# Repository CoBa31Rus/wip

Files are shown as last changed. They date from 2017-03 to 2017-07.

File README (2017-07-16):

Терморегулятор для инкубатора в стадии разработки.
Построен на atmega8 + LCD1602, 3 кнопки, 3 транзистора один из которых задействован как ШИМ.
Схема пока что тестируется
Цель: создание терморегулятора для инкубатора, возможно с дополнительными ф-ями(переворот, влажность....)
Чем отличаемся от тясячь других? Нужен регулятор который может работать от 12в т.к. используется там где могут отключать свет долгосрочно

Цели:
  1. ~~Перенос опроса DS18B20 на таймер вместо задержек.~~
  2. Обновление данных на экране по мере поступления.
  3. ~~Реализация ПИД регулятора.~~
  4. ~~Вывод параметров в виде простого меню.~~
  5. ~~Редактирование параметров.~~
  6. ~~Сохранение параметров в EEPROM~~
  7. Generate EEPROM from make

Change:
  16.07.2017
	1.Delete eeprom.c eeprom.h (Use from std AVR library)
	2.Delete old Makefile (work fine)
	3.Fix main.c for new eeprom func
	4.Add eeprom create and upload
  12.07.2017
  	1. New Makefile, generate by standart WinAVR Mfile.
	2. Fix warning with lcd.h
	3. add #DEBUG for global val pid
	4. add generate eeprom (but now is empty)
  25.06.2017
  	1. fix bug's with PID (now PID is work normal)
	2. add function "DEBUG" with USART (send temp for change PID coefficient, just Define DEBUG)
	
  26.03.2017:
	1. add hardware
	2. modify hardware
  22.04.2017
	1. Fix temperature bug
	2. Size 4.3 -> 2.6
	3. Delete sprintf
	4. New onewire files

!!PS!! Sorry for my English =)

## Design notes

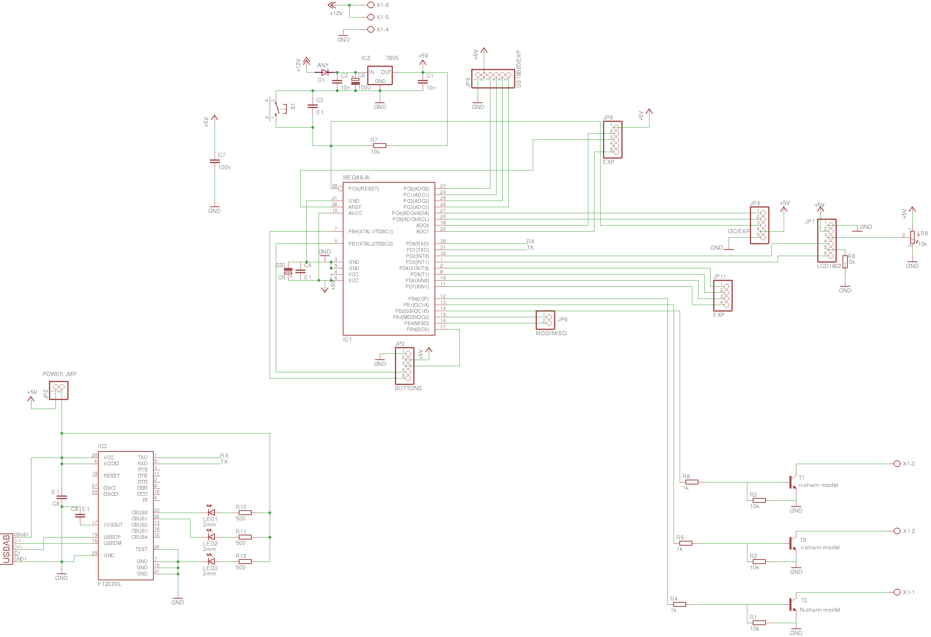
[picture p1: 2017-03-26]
LCD+DS18B20/hardware/img.png

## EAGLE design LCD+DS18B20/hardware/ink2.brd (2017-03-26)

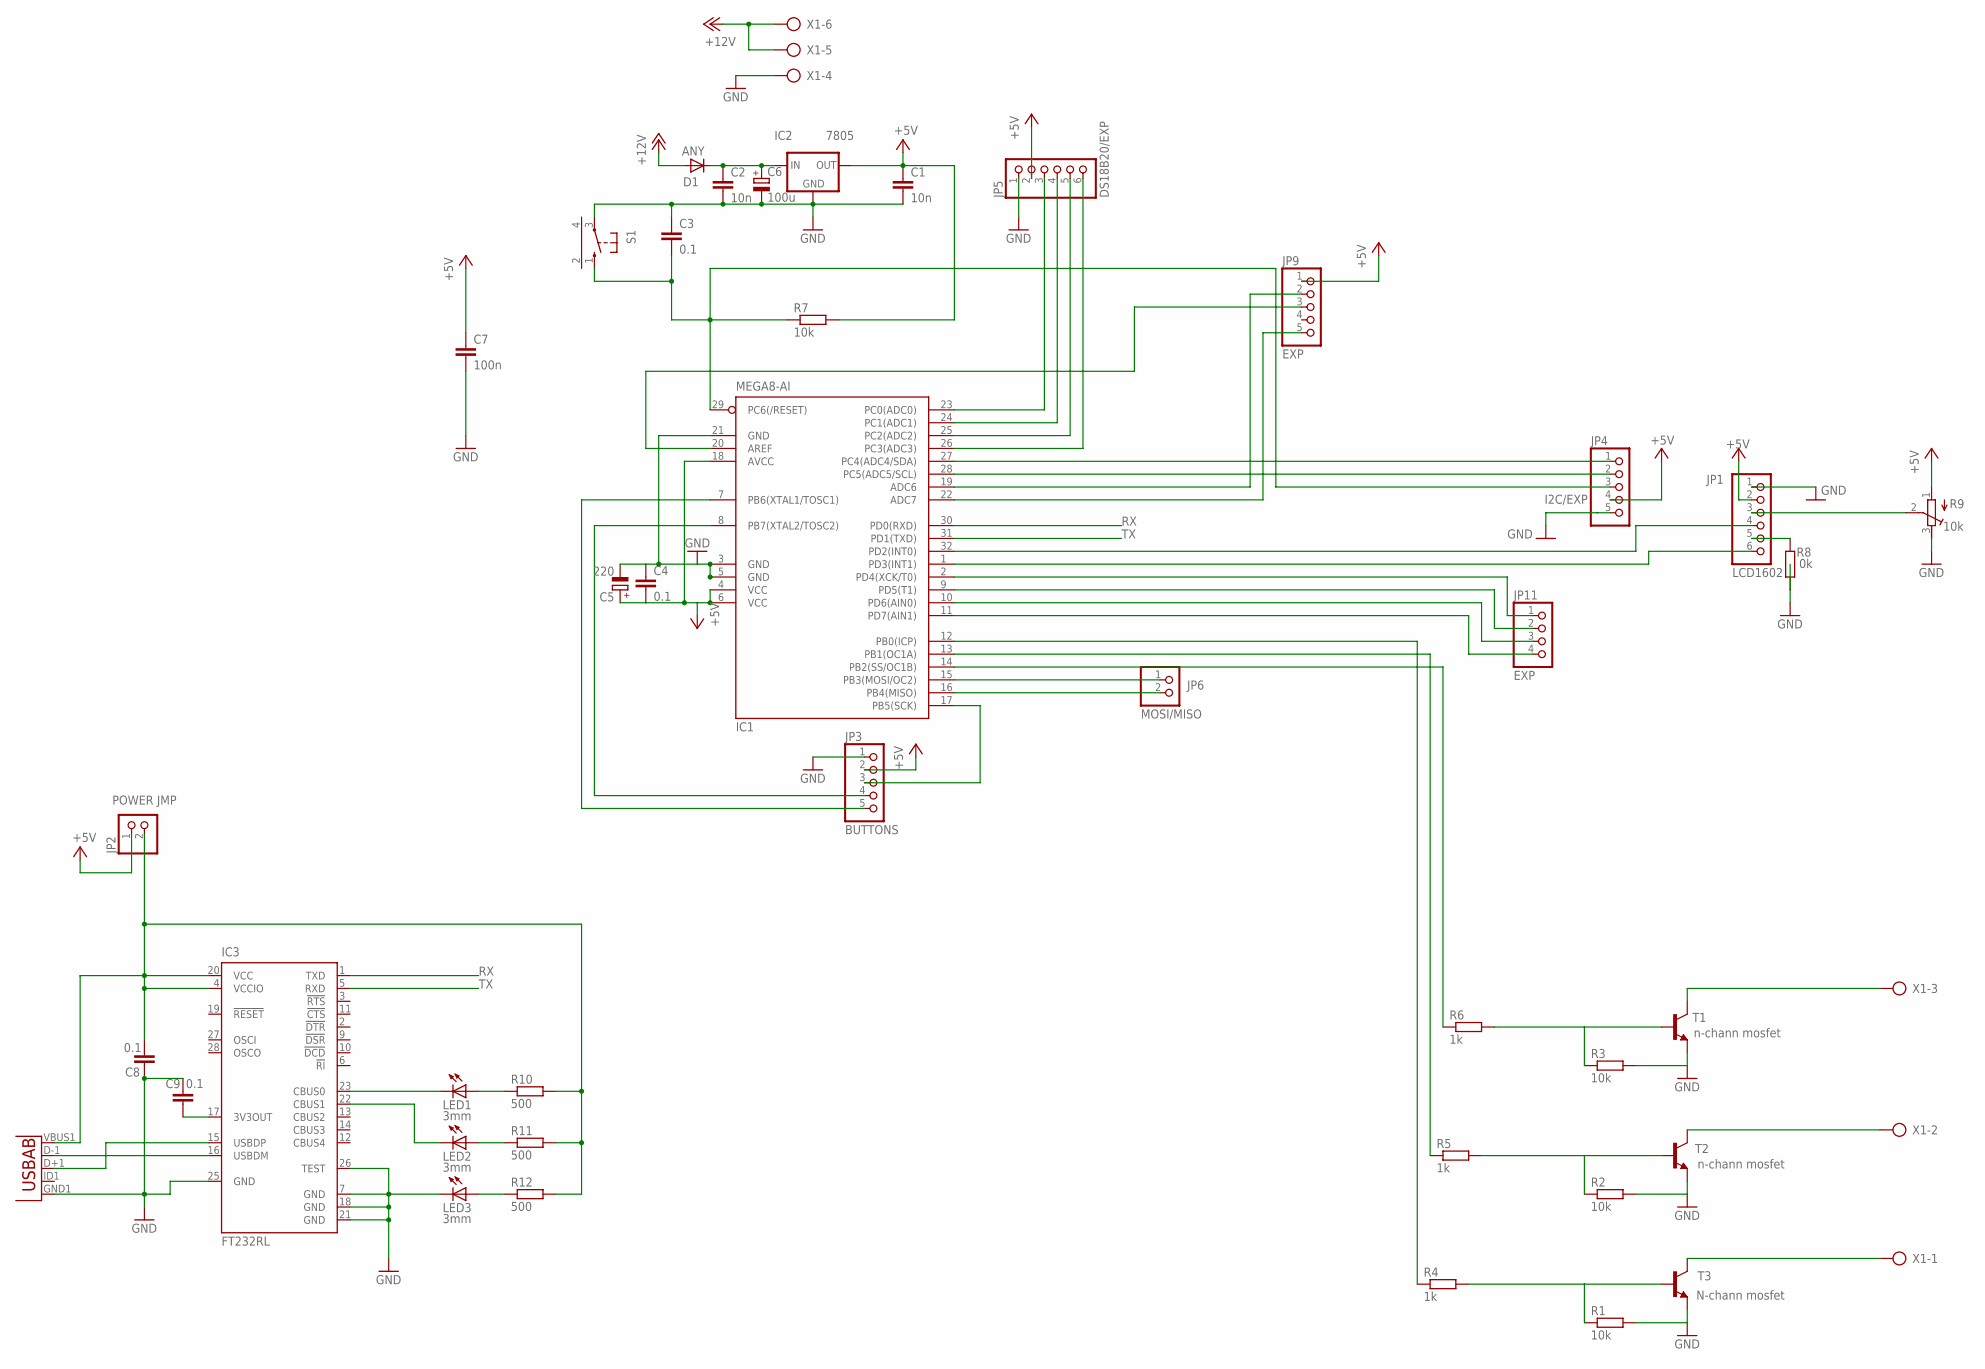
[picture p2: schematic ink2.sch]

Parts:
ANY: D1; SOD-123_MINI-SMA
C1, C2: 10n; C1206
C3, C4, C8, C9: 0.1; C1206
C5: 220; 175TMP-0808
C6: 100u; 140CLH-1010
C7: 100n; C1206K
IC1: MEGA8-AI; TQFP32-08
IC2: 7805; DPACK
IC3: FT232RL; SSOP28
JP1: LCD1602; 1X06
JP2: POWER JMP; 1X02
JP3: BUTTONS; 1X05
JP4: I2C/EXP; 1X05
JP5: DS18B20/EXP; 1X06
JP6: MOSI/MISO; 1X02
JP9: EXP; 1X05
JP11: EXP; 1X04
LED1, LED2, LED3: 3mm; LED3MM
R1, R2, R3, R7: 10k; M1206
R4, R5, R6: 1k; M1206
R8: 0k; M1206
R9: 10k; RTRIM64Y
R10, R11, R12: 500; M1206
S1: 10-XX-RPAD; B3F-10XX-RPAD
T1, T2: n-chann mosfet; DPAK
T3: N-chann mosfet; DPAK
U1: USB""; USB-MICRO-SMD
X1: AK300/6

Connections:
+5V: C1.1, C4.2, C5.+, C7.1, IC1.4 (VCC), IC1.6 (VCC), IC1.18 (AVCC), IC2.3 (OUT), JP1.2, JP2.1, JP3.2, JP4.4, JP5.2, JP9.1, R7.2, R9.1 (A)
+12V: ANY.A, X1.5, X1.6
GND: C1.2, C2.2, C3.1, C4.1, C5.-, C6.-, C7.2, C8.2, C9.2, IC1.3 (GND), IC1.5 (GND), IC1.21 (GND), IC2.4 (GND), IC3.7 (GND), IC3.18 (GND), IC3.21 (GND), IC3.25 (GND), IC3.26 (TEST), JP1.1, JP3.1, JP4.5, JP5.1, LED3.K (C), R1.2, R2.2, R3.2, R8.2, R9.3 (E), S1.3, T1.3 (E), T2.3 (E), T3.3 (E), U1.GND1 (GND), X1.4
unnamed: IC1.11 (PD7(AIN1)), JP11.4
unnamed: IC1.1 (PD3(INT1)), JP1.6
unnamed: IC1.2 (PD4(XCK/T0)), JP11.1
unnamed: ANY.C, C2.1, C6.+, IC2.1 (IN)
unnamed: IC1.15 (PB3(MOSI/OC2)), JP6.1
unnamed: JP1.3, R9.2 (S)
unnamed: IC1.17 (PB5(SCK)), JP3.3
unnamed: IC1.16 (PB4(MISO)), JP6.2
unnamed: IC1.8 (PB7(XTAL2/TOSC2)), JP3.4
unnamed: IC1.7 (PB6(XTAL1/TOSC1)), JP3.5
unnamed: R1.1, R4.2, T3.1 (B)
unnamed: R2.1, R5.2, T2.1 (B)
unnamed: R3.1, R6.2, T1.1 (B)
unnamed: IC1.10 (PD6(AIN0)), JP11.3
unnamed: IC1.9 (PD5(T1)), JP11.2
unnamed: IC1.14 (PB2(SS/OC1B)), R6.1
unnamed: IC1.27 (PC4(ADC4/SDA)), JP4.1
unnamed: IC1.28 (PC5(ADC5/SCL)), JP4.2
unnamed: IC1.23 (PC0(ADC0)), JP5.3
unnamed: T1.4 (C), X1.3
unnamed: T2.4 (C), X1.2
unnamed: T3.4 (C), X1.1
unnamed: IC1.24 (PC1(ADC1)), JP5.4
unnamed: IC1.25 (PC2(ADC2)), JP5.5
unnamed: IC1.26 (PC3(ADC3)), JP5.6
unnamed: IC1.32 (PD2(INT0)), JP1.4
unnamed: IC3.23 (CBUS0), LED1.K (C)
unnamed: IC3.16 (USBDM), U1.D-1 (D-)
unnamed: IC1.20 (AREF), JP9.3
unnamed: IC1.19 (ADC6), JP9.2
unnamed: IC1.22 (ADC7), JP9.5
unnamed: IC3.22 (CBUS1), LED2.K (C)
unnamed: LED2.A, R11.1
unnamed: IC1.13 (PB1(OC1A)), R5.1
unnamed: IC1.12 (PB0(ICP)), R4.1
unnamed: JP1.5, R8.1
unnamed: IC3.15 (USBDP), U1.D+1 (D+)
unnamed: LED1.A, R10.1
unnamed: C9.1, IC3.17 (3V3OUT)
unnamed: C8.1, IC3.4 (VCCIO), IC3.20 (VCC), JP2.2, R10.2, R11.2, R12.2, U1.VBUS1 (VBUS)
unnamed: LED3.A, R12.1
RESET: C3.2, IC1.29 (PC6(/RESET)), JP4.3, R7.1, S1.1 (S)
RX: IC1.30 (PD0(RXD)), IC3.1 (TXD)
TX: IC1.31 (PD1(TXD)), IC3.5 (RXD)

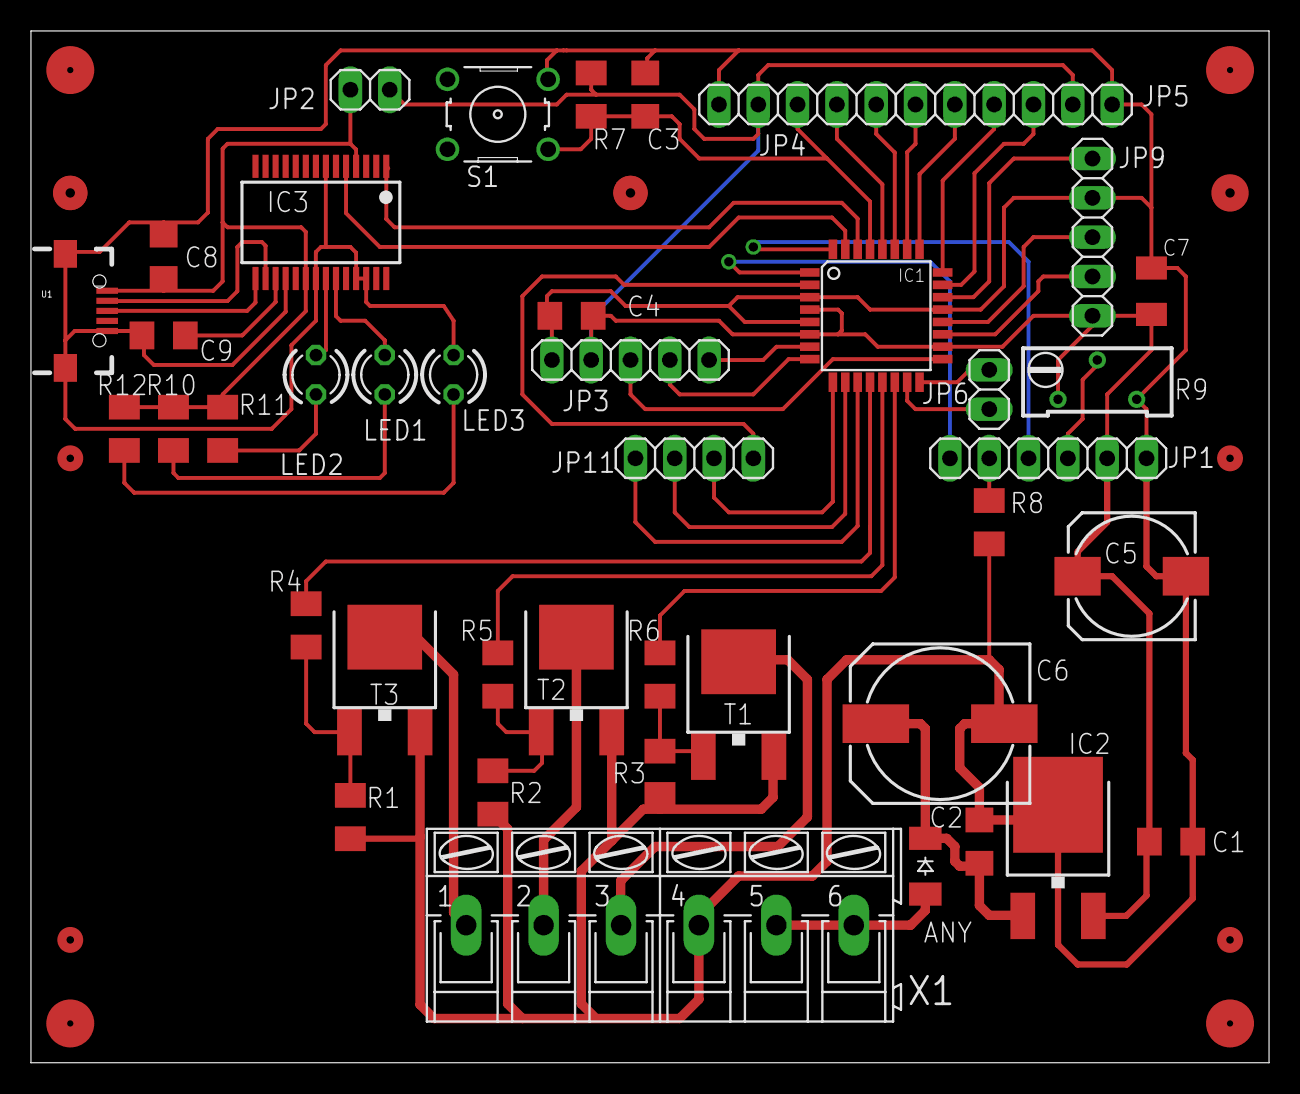
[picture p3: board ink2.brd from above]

Board: 2 copper layers, 80.0 x 66.7 mm, 42 parts (0 on the bottom side), 47 nets.

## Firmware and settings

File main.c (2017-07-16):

/*
 * main.c
 *
 *  Created on: 07.11.2016
 *      Author: coba31rus
 */

#include <avr/eeprom.h>
#include "main.h"

//#define DEBUG

int real_temperature, need_temperature;
volatile unsigned char buffer_key_ovf = 0, buffer_tem_ovf = 0, tmp_buttons, pushed_buttons, menu = 0, selected = 0, show_time = 0;
unsigned char pK, iK, dK;
unsigned char EEMEM eep_pK = 60, eep_iK = 20, eep_dK = 80;
uint16_t EEMEM eep_need_temperature = 600;
char h_string[15], l_string[15];
unsigned char cou = 0;

#ifdef DEBUG
extern int pres, ires, dres;
#endif
void sysinit(void){
	//Таймер обработчик клавиш; Timer for Key
		//Настройка таймера
	TIMSK |= (1<<TOIE0);
	TCCR0 |= (1<<CS00)|(0<<CS01)|(1<<CS02); //0,03264 ms
		//Настройка порта на ввод
	DDRB &= ~1<<7;
	DDRB &= ~1<<6;
	DDRB &= ~1<<5;
	sei();
	//ШИМ
	DDRB|=0x02;
	TCCR1A|=(1<<COM1A1)|(1<<WGM10);
	TCCR1B|=(1<<WGM12)|(1<<CS12)|(0<<CS11)|(0<<CS10);
	HEATER=0;
	//Дисплей
	lcd_init();
	//Порт 1Wire
	ONEWIRE_PORT &= ~_BV(ONEWIRE_PIN_NUM);
	//ПИД регулятор
	pK = eeprom_read_byte(&eep_pK);
	iK = eeprom_read_byte(&eep_iK);
	dK = eeprom_read_byte(&eep_dK);
	need_temperature = eeprom_read_word(&eep_need_temperature);
	//pK = EEPROM_read_char(0x0);
	//iK = EEPROM_read_char(0x1);
	//dK = EEPROM_read_char(0x2);
	//need_temperature = EEPROM_read_int(0x3);

	//pK = 40;
	//iK = 20;
	//dK = 80;
	//need_temperature = 600;
#ifdef DEBUG
	#define BAUD 9600L
	#define UBRRL_value (F_CPU/(BAUD*16))-1
	UCSRB |= (1<<TXEN);
	UBRRL = UBRRL_value;
	UBRRH = UBRRL_value >> 8;
	UCSRC |= (1<<URSEL)|(1<<UCSZ0)|(1<<UCSZ1);
#endif

}

#ifdef DEBUG
void send_int_UART(int val){
	while(!(UCSRA & (1<<UDRE)));
	UDR = (char)val>>8;
	while(!(UCSRA & (1<<UDRE)));
	UDR = (char)val;
}
#endif

void key_plus(void){
	switch (menu){
		case 0:
			menu++;
			break;
		case 1:
			if(selected)
				need_temperature++;
			else
				menu++;
			break;
		case 2:
			if(selected)
				pK++;
			else
				menu++;
			break;
		case 3:
			if(selected)
				iK++;
			else
				menu++;
			break;
		case 4:
			if(selected)
				dK++;
			else
				menu++;
			break;
	}
	if(menu > MENUCOUNT)
		if(!selected)
			menu = 0;
}

void key_minus(void){
	switch (menu){
		case 0:
			menu--;
			break;
		case 1:
			if(selected)
				need_temperature--;
			else
				menu--;
			break;
		case 2:
			if(selected)
				pK--;
			else
				menu--;
			break;
		case 3:
			if(selected)
				iK--;
			else
				menu--;
			break;
		case 4:
			if(selected)
				dK--;
			else
				menu--;
			break;
	}
	if(menu > MENUCOUNT)
		if(!selected)
			menu = MENUCOUNT;
}

ISR(TIMER0_OVF_vect){
	if (buffer_key_ovf >= OVF_BUF_COUNT){ //Срабатывание 0.03264 * OVF_BUF_COUNT ms
		tmp_buttons = pushedButton(PINB>>5);
		if (tmp_buttons != KEY_UNP){
			pushed_buttons = tmp_buttons;
			if(pushed_buttons == KEY_UP){
				while((PINB>>5)!=KEY_UNP);
				key_plus();
				pushed_buttons = KEY_UNP;
			}
			if(pushed_buttons == KEY_DOW){
				while((PINB>>5)!=KEY_UNP);
				key_minus();
				pushed_buttons = KEY_UNP;
			}
			if(pushed_buttons == KEY_CEN){
				while((PINB>>5)!=KEY_UNP);
				if(menu != 0){
					if(selected){
						eeprom_write_byte(&eep_pK, pK);
						eeprom_write_byte(&eep_iK, iK);
						eeprom_write_byte(&eep_dK, dK);
						eeprom_write_word(&eep_need_temperature, need_temperature);
						//EEPROM_write(0x0, pK);
						//EEPROM_write(0x1, iK);
						//EEPROM_write(0x2, dK);
						//EEPROM_write_int(0x3, need_temperature);
					}
					selected = !selected;
				}
				pushed_buttons = KEY_UNP;
			}
		}
		else
			pushed_buttons = KEY_UNP;
		buffer_key_ovf = 0;
	}

	buffer_tem_ovf++;
	buffer_key_ovf++;
	show_time++;
}

int main(void){
	sysinit();
	while(1){
		if(buffer_tem_ovf >= TEMP_UPDATE){
			real_temperature = readtt_2();
			if(real_temperature == 0){
				cou = 0;
			}
			else{
				cou = calc_pwm(need_temperature, real_temperature);
			}
			HEATER = cou;
			buffer_tem_ovf = 0;
			#ifdef DEBUG
				send_int_UART(real_temperature);
			#endif
		}
		 if(show_time >= SCREEN_UPDATE){
			switch (menu){
				case 0:
					h_string[0] = *"t";
					h_string[1] = *"=";
					h_string[2] = (real_temperature>>4)/10 + 0x30;
					h_string[3] = (real_temperature>>4)%10 + 0x30;
					h_string[4] = *",";
					h_string[5] = (real_temperature%16)*625/1000 + 0x30;
					h_string[6] = ((real_temperature%16)*625/100)%10 + 0x30;
					h_string[7]	= *"\0";

					l_string[0] = *"H";
					l_string[1] = *"=";
					l_string[2] = cou/100 + 0x30;
					l_string[3] = (cou/10)%10 + 0x30;
					l_string[4] = cou%10 + 0x30;
					l_string[5] = *"\0";
					break;
				case 1:
					h_string[0] = *"s";
					h_string[1] = *"e";
					h_string[2] = *"t";
					h_string[3] = *" ";
					h_string[4] = *"t";
					h_string[5] = *"e";
					h_string[6] = *"m";
					h_string[7] = *"p";
					h_string[8] = *":";
					h_string[9]	= *"\0";

					l_string[0] = *" ";
					l_string[1] = (need_temperature>>4)/10 + 0x30;
					l_string[2] = (need_temperature>>4)%10 + 0x30;
					l_string[3] = *",";
					l_string[4] = (need_temperature%16)*625/1000 + 0x30;
					l_string[5] = ((need_temperature%16)*625/100)%10 + 0x30;
					l_string[6] = *"\0";
					break;
				case 2:
					h_string[0] = *"s";
					h_string[1] = *"e";
					h_string[2] = *"t";
					h_string[3] = *" ";
					h_string[4] = *"k";
					h_string[5] = *"p";
					h_string[6] = *"\0";

					l_string[0] = *" ";
					l_string[1] = pK/100 + 0x30;
					l_string[2] = (pK/10)%10 + 0x30;
					l_string[3] = pK%10 + 0x30;
#ifndef DEBUG
					l_string[4] = *"\0";
#endif
#ifdef DEBUG
					l_string[4] = *" ";
					l_string[5] = (pres/10000)+0x30;
					l_string[6] = (pres/1000)%10 + 0x30;
					l_string[7] = (pres/100)%10 + 0x30;
					l_string[8] = (pres/10)%10 + 0x30;
					l_string[9] = pres%10 + 0x30;
#endif
					break;
				case 3:
					h_string[0] = *"s";
					h_string[1] = *"e";
					h_string[2] = *"t";
					h_string[3] = *" ";
					h_string[4] = *"k";
					h_string[5] = *"i";
					h_string[6]	= *"\0";

					l_string[0] = *" ";
					l_string[1] = iK/100 + 0x30;
					l_string[2] = *".";
					l_string[3] = (iK/10)%10 + 0x30;
					l_string[4] = iK%10 + 0x30;
#ifndef DEBUG
					l_string[5] = *"\0";
#endif
#ifdef DEBUG
					l_string[5] = *" ";
					l_string[6] = (ires/10000)+0x30;
					l_string[7] = (ires/1000)%10 + 0x30;
					l_string[8] = (ires/100)%10 + 0x30;
					l_string[9] = (ires/10)%10 + 0x30;
					l_string[10] = ires%10 + 0x30;
#endif
					break;
				case 4:
					h_string[0] = *"s";
					h_string[1] = *"e";
					h_string[2] = *"t";
					h_string[3] = *" ";
					h_string[4] = *"k";
					h_string[5] = *"d";
					h_string[6]	= *"\0";

					l_string[0] = *" ";
					l_string[1] = dK/100 + 0x30;
					l_string[2] = (dK/10)%10 + 0x30;
					l_string[3] = dK%10 + 0x30;
#ifndef DEBUG
					l_string[4] = *"\0";
#endif
#ifdef DEBUG
					l_string[4] = *" ";
					l_string[5] = (dres/10000)+0x30;
					l_string[6] = (dres/1000)%10 + 0x30;
					l_string[7] = (dres/100)%10 + 0x30;
					l_string[8] = (dres/10)%10 + 0x30;
					l_string[9] = dres%10 + 0x30;
#endif
					break;
			}
		show_time = 0;
		if(selected)
			if(menu)
				l_string[0] = 0x3E;
		lcd_clear();
		lcd_str_out(h_string);
		lcd_gotoxy(0,1);
		lcd_str_out(l_string);
		}
		delay_ms(1);
	}
	return 0;
}

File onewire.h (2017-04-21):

/*
 * 1wire.h
 *
 *  Created on: 08.11.2016
 *      Author: coba31rus
 */

#ifndef ONEWIRE_H_
	#define ONEWIRE_H_

	#include <avr/io.h>
	#include <util/delay.h>

	#define ONEWIRE_PORT PORTC
	#define ONEWIRE_DDR DDRC
	#define ONEWIRE_PIN PINC
	#define ONEWIRE_PIN_NUM PC0
	#define ONEWIRE_LOW ONEWIRE_DDR |= (1<<ONEWIRE_PIN_NUM)
	#define ONEWIRE_HIGH ONEWIRE_DDR &= ~(1<<ONEWIRE_PIN_NUM)
	#define ONEWIRE_LEVEL ONEWIRE_PIN & (1 << ONEWIRE_PIN_NUM)

	#define SEI asm("sei")
	#define CLI asm("cli")

	#define delay_us(_data)	_delay_us(_data)
	#define delay_ms(_data)	_delay_ms(_data)

	int readtt_2(void);

#endif /* 1WIRE_H_ */

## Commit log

2017-01-13 Стартую
2017-01-13 Исправил инклЮды
2017-01-13 Добавлены фун-ции записи/чтения в EEPROM и файлы eeprom.c eeprom.h
2017-01-13 Вывод дробной части без float. В режиме тестирования
2017-01-13 Оптимизирована ф-я вывода температуры.
2017-01-13 Добавлен класс button, ф-я антидребезг
2017-01-14 Прикрутил Таймер, опрос кнопок, с тестом
2017-01-14 Обработка средней кнопки
2017-01-14 Добавлен низкочастотный ШИМ, переименованы перепенные
2017-01-14 Добавлен класс PID + ф-я П регулятора
2017-01-14 Добален README
2017-01-14 Обновлен README
2017-01-16 Дописан ПИД, требует настройки
2017-01-16 Перенос опроса PID на таймер ~6.5сек
2017-01-16 Переписал PID
2017-01-17 Исправления: PID, обработчик кнопок
    [main.c]
2017-01-18 Опрос датчика ds18b20 в таймере
2017-01-19 При ошибке по шине 1wire отключается нагрев
2017-01-19 Закоментировал не используемые ф-ии
2017-01-19 Добавил ф-ю чтения INT пока не используется
2017-01-19 Поправил вывод редактируемого параметра
2017-01-19 Добавлена настройка периода пересчета ПИД
2017-01-24 Чтение запись настроек в епром
2017-01-24 Добавлен файл eep
2017-01-27 Добавлен простой Makefile убраны не нужные папки
2017-01-27 игнор
2017-01-27 Игнор++
2017-01-27 Удалены лищние файлы
2017-01-27 Удалены еще лищние файлы
2017-01-27 Обновлен .ignore
2017-03-26 add hardware(PCB in eagle 8)
    [ink2.brd, ink2.sch]
2017-03-26 fix add hardware(PCB in eagle 8)
    [main.c]
2017-04-21 lot of bug fixes, reduced bin size, removed dependency sprintf, rewritten onewire
    [main.c, onewire.h]
2017-06-25 fix bugs and add DEBUG USART function
    [main.c, onewire.h]
2017-06-25 fix load from EEPROM
    [main.c]
2017-07-12 Fix some bugs
    add new makefile, fix lcd warning, main global defines and DEBUG func
    [main.c]
2017-07-12 fix
    comment default val of PID coeff
    [main.c]
